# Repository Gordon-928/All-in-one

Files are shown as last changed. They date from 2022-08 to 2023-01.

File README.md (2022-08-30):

# All-in-one
Design and program of a small package data collection device
This project aims to learn the bascis of using STM32 MCU and PCB layout with MCU and sensors. The ultimate goal of the project is to develope a all-in-one sensor to collect flight data of a rocket, drop tests and other possible usage. Personal goal is to make a sensor close to commercial grade with all well-thought start-up sequence, easy to use and robust software.

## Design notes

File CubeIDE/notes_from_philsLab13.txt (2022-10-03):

STM32 CUBEIDE
CLOCK SETTING
- Set required clock source and run clock solver

SPI SETTING
- Change prescaler to change the baud rate (this step is mainly to tune to the required baud rate)

TIMER SETTING - PWM
- Change prescaler to change PWM freq
- This depends on the clock that the timer is on, refer to datasheet
- Look for the clock frequecny and change the prescaler to achieve desired frequency
	- e.g: want to scale down the timer clock from 84 MHz (APB1) to 10 Hz
	       i) Prescaler set to => 8400-1 (84e6 / 8400 = 10k) //set the freq of the counter is changed
              ii) counter period set to 100-1 (10k/100 = 100Hz) //counter need to count to 100-1
              Note: 
 	      - the -1 offset is needed (counter start from 0, if we want a 16 bit timer to count 2^16 times, it just need to count from 0-2^16-1)
              - must check if counter exceed the size of the regiester xxbit timer (e.g. 16 bit timer has a max value of 2^16 = 65536)

link: https://electronics.stackexchange.com/questions/632838/prescaler-vs-counter-period-stm32
Ref: ST-AN4776 Rev 3 Applcation Notes

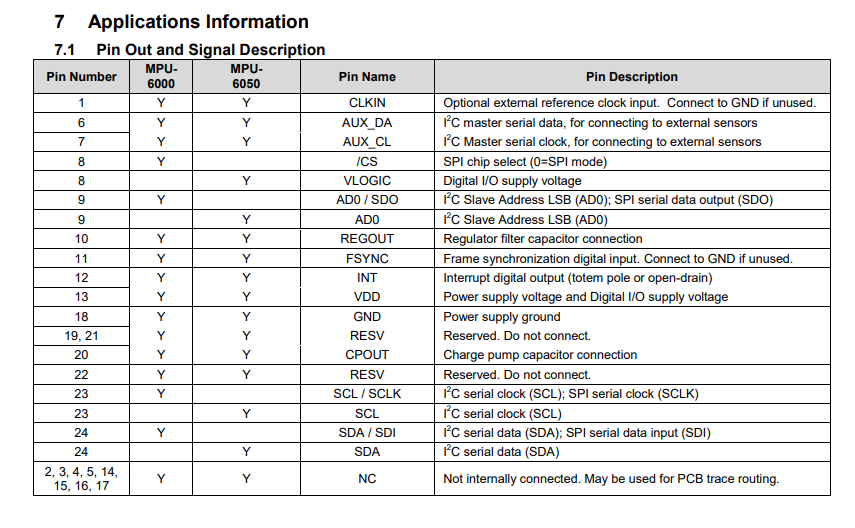
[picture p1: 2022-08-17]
Datasheets/MPU6050 Pinout.png

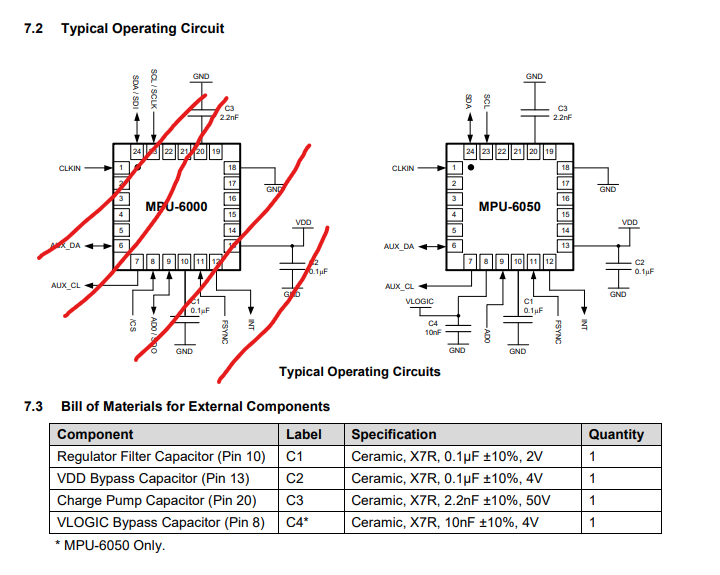
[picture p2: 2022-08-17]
Datasheets/MPU6050 Typical Circuit.png

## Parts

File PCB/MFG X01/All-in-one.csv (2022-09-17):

Item | Qty | Reference(s) | Value | LibPart | Footprint | Datasheet | JLCPCB Part# | LCSC | LCSC Part | PART ID
1 | 2 | C1, C3 | 22u | Device:C_Small | Capacitor_SMD:C_1206_3216Metric | ~ |  | C12891
2 | 1 | C2 | 1u | Device:C_Small | Capacitor_SMD:C_0805_2012Metric | ~ |  | C2798196
3 | 8 | C4, C8, C9, C10, C11, C16, C18, C19 | 100n | Device:C_Small | Capacitor_SMD:C_0402_1005Metric | ~ | C307331 | C307331 | C307331
4 | 1 | C5 | 1u | Device:C_Small | Capacitor_SMD:C_0603_1608Metric | ~ | C15849 | C15849 | C15849
5 | 2 | C6, C17 | 10n | Device:C_Small | Capacitor_SMD:C_0402_1005Metric | ~ | C15195 | C15195 | C15195
6 | 2 | C7, C14 | 4u7 | Device:C_Small | Capacitor_SMD:C_0603_1608Metric | ~ | C19666 | C19666 | C19666
7 | 2 | C12, C13 | 12p | Device:C_Small | Capacitor_SMD:C_0402_1005Metric | ~ | C1547 | C1547 | C1547
8 | 1 | C15 | 10u | Device:C_Small | Capacitor_SMD:C_0603_1608Metric | ~ | C96446 | C96446 | C96446
9 | 1 | C20 | 2n2 | Device:C_Small | Capacitor_SMD:C_0402_1005Metric | ~ | C1531 | C1531 | C1531
10 | 1 | D1 | B5819W | Device:D_Schottky_Small | Diode_SMD:D_SOD-123 | ~ | C8598 | C8598 | C8598
11 | 1 | D2 | LED_RED | Device:LED_Small | LED_SMD:LED_0603_1608Metric | ~ |  | C965799
12 | 1 | D3 | LED_GREEN | Device:LED | LED_SMD:LED_0603_1608Metric | ~ | C87326 | C965805 | C87326
13 | 1 | F1 | 250mA | Device:Polyfuse | Fuse:Fuse_1206_3216Metric | ~ | C269113 | C269113 | C269113 | SMD1206B025TF/24
14 | 1 | FB1 | 600 @ 100MHz | Device:FerriteBead_Small | Inductor_SMD:L_1206_3216Metric | ~ | C73732 | C73732 | C73732
15 | 4 | H1, H2, H3, H4 | MountingHole_Pad | Mechanical:MountingHole_Pad | MountingHole:MountingHole_3.5mm_Pad_Via | ~
16 | 1 | J1 | HIGH VOLTAGE | Connector:Screw_Terminal_01x02 | TerminalBlock_TE-Connectivity:TerminalBlock_TE_282834-2_1x02_P2.54mm_Horizontal | ~
17 | 1 | J2 | Micro_SD_Card_Det | Connector:Micro_SD_Card_Det | All-in-one-custom:SD_Card_custom | https://www.hirose.com/product/en/download_file/key_name/DM3/category/Catalog/doc_file_id/49662/?item_id=195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
18 | 1 | J3 | USB_C_Receptacle_USB2.0 | Connector:USB_C_Receptacle_USB2.0 | All-in-one-custom:USB_C_16PIN | https://www.usb.org/sites/default/files/documents/usb_type-c.zip
19 | 1 | J4 | I2C_EXT | Connector_Generic:Conn_01x04 | Connector_PinHeader_2.54mm:PinHeader_1x04_P2.54mm_Vertical | ~
20 | 1 | J5 | GPIO | Connector_Generic:Conn_01x04 | Connector_PinHeader_2.54mm:PinHeader_1x04_P2.54mm_Vertical | ~
21 | 1 | J6 | SWD | Connector_Generic:Conn_02x05_Odd_Even | Connector_PinHeader_2.54mm:PinHeader_2x05_P2.54mm_Vertical | ~
22 | 2 | J7, J8 | Conn_01x02 | Connector_Generic:Conn_01x02 | Connector_PinHeader_2.54mm:PinHeader_1x02_P2.54mm_Vertical | ~
23 | 1 | J9 | UART_EXT | Connector_Generic:Conn_01x04 | Connector_PinHeader_2.54mm:PinHeader_1x04_P2.54mm_Vertical | ~
24 | 1 | L1 | 22u | Device:L_Small | All-in-one-custom:MPIT8040 | ~ |  | C281320
25 | 1 | L2 | 39n | Device:L_Small | Inductor_SMD:L_0402_1005Metric | ~ | C86063 | C86063 | C86063
26 | 1 | Q1 | AO3401A | Transistor_FET:AO3401A | Package_TO_SOT_SMD:SOT-23 | http://www.aosmd.com/pdfs/datasheet/AO3401A.pdf | C15127 | C15127 | C15127
27 | 1 | R1 | 75k | Device:R_Small | Resistor_SMD:R_0603_1608Metric | ~ |  | C18671
28 | 1 | R2 | 40k2 | Device:R_Small | Resistor_SMD:R_0603_1608Metric | ~ |  | C25893
29 | 2 | R3, R4 | 13k | Device:R_Small | Resistor_SMD:R_0603_1608Metric | ~ |  | C2907101
30 | 3 | R5, R8, R11 | 10k | Device:R_Small | Resistor_SMD:R_0402_1005Metric | ~ | C25744 | C25744 | C25744
31 | 1 | R6 | 510 | Device:R_Small | Resistor_SMD:R_0402_1005Metric | ~ | C25123 | C25123 | C25123
32 | 1 | R7 | 1k | Device:R_Small | Resistor_SMD:R_0603_1608Metric | ~ | C21190 | C21190 | C21190
33 | 2 | R9, R10 | 2k2 | Device:R_Small | Resistor_SMD:R_0603_1608Metric | ~ | C4190 | C4190 | C4190
34 | 2 | R12, R13 | 5k1 | Device:R_Small | Resistor_SMD:R_0402_1005Metric | ~ | C25905 | C25905 | C25905
35 | 1 | SW1 | SW_Push | Switch:SW_Push | All-in-one-custom:GT-TC029 | ~ | C843669 | C843669 | C843669
36 | 1 | SW2 | BOOT | Switch:SW_Push | All-in-one-custom:GT-TC029 | ~ | C843669 | C843669 | C843669
37 | 1 | U1 | TPMP1470 | All-in-one_custom:TPMP1470 | Package_TO_SOT_SMD:SOT-23-6 |  |  | C558426
38 | 1 | U2 | STM32F401CDUx | MCU_ST_STM32F4:STM32F401CDUx | Package_DFN_QFN:QFN-48-1EP_7x7mm_P0.5mm_EP5.6x5.6mm | http://www.st.com/st-web-ui/static/active/en/resource/technical/document/datasheet/DM00102166.pdf
39 | 1 | U3 | BMP280 | Sensor_Pressure:BMP280 | Package_LGA:Bosch_LGA-8_2x2.5mm_P0.65mm_ClockwisePinNumbering | https://ae-bst.resource.bosch.com/media/_tech/media/datasheets/BST-BMP280-DS001.pdf
40 | 1 | U4 | MPU-6050 | Sensor_Motion:MPU-6050 | Sensor_Motion:InvenSense_QFN-24_4x4mm_P0.5mm | https://store.invensense.com/datasheets/invensense/MPU-6050_DataSheet_V3%204.pdf
41 | 1 | U5 | USBLC6-2P6 | Power_Protection:USBLC6-2P6 | Package_TO_SOT_SMD:SOT-666 | https://www.st.com/resource/en/datasheet/usblc6-2.pdf | C2827693 | C2827693 | C2827693
42 | 1 | Y1 | 25MHz 12pF | Device:Crystal_GND24_Small | Crystal:Crystal_SMD_3225-4Pin_3.2x2.5mm | ~ | C9006 | C9006 | C9006 | X322525MOB4SI

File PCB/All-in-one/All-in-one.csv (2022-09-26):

Qty | LCSC Part Number
2 | C13585
1 | C24497
3 | C28233
2 | C12891
8 | C307331
1 | C15849
2 | C15195
2 | C19666
2 | C1547
1 | C96446
1 | C1531
3 | C15850
1 | C8598
1 | C72041
1 | C2286
1 | C87326
2 | C269113
1 | C73732
4
1
1
1
1
1
2
1
1
1
1 | C135262
1 | C86063
1 | C15127
1 | C23003
3 | C25804
1 | C22843
2 | C22797
2 | C21190
3 | C25744
1 | C25123
2 | C4190
2 | C25905
1 | C145841
1 | C843669
1 | C843669
1 | C116592
1 | C133056
1
1
1
1 | C2827693
2 | C89855
1 | C9006

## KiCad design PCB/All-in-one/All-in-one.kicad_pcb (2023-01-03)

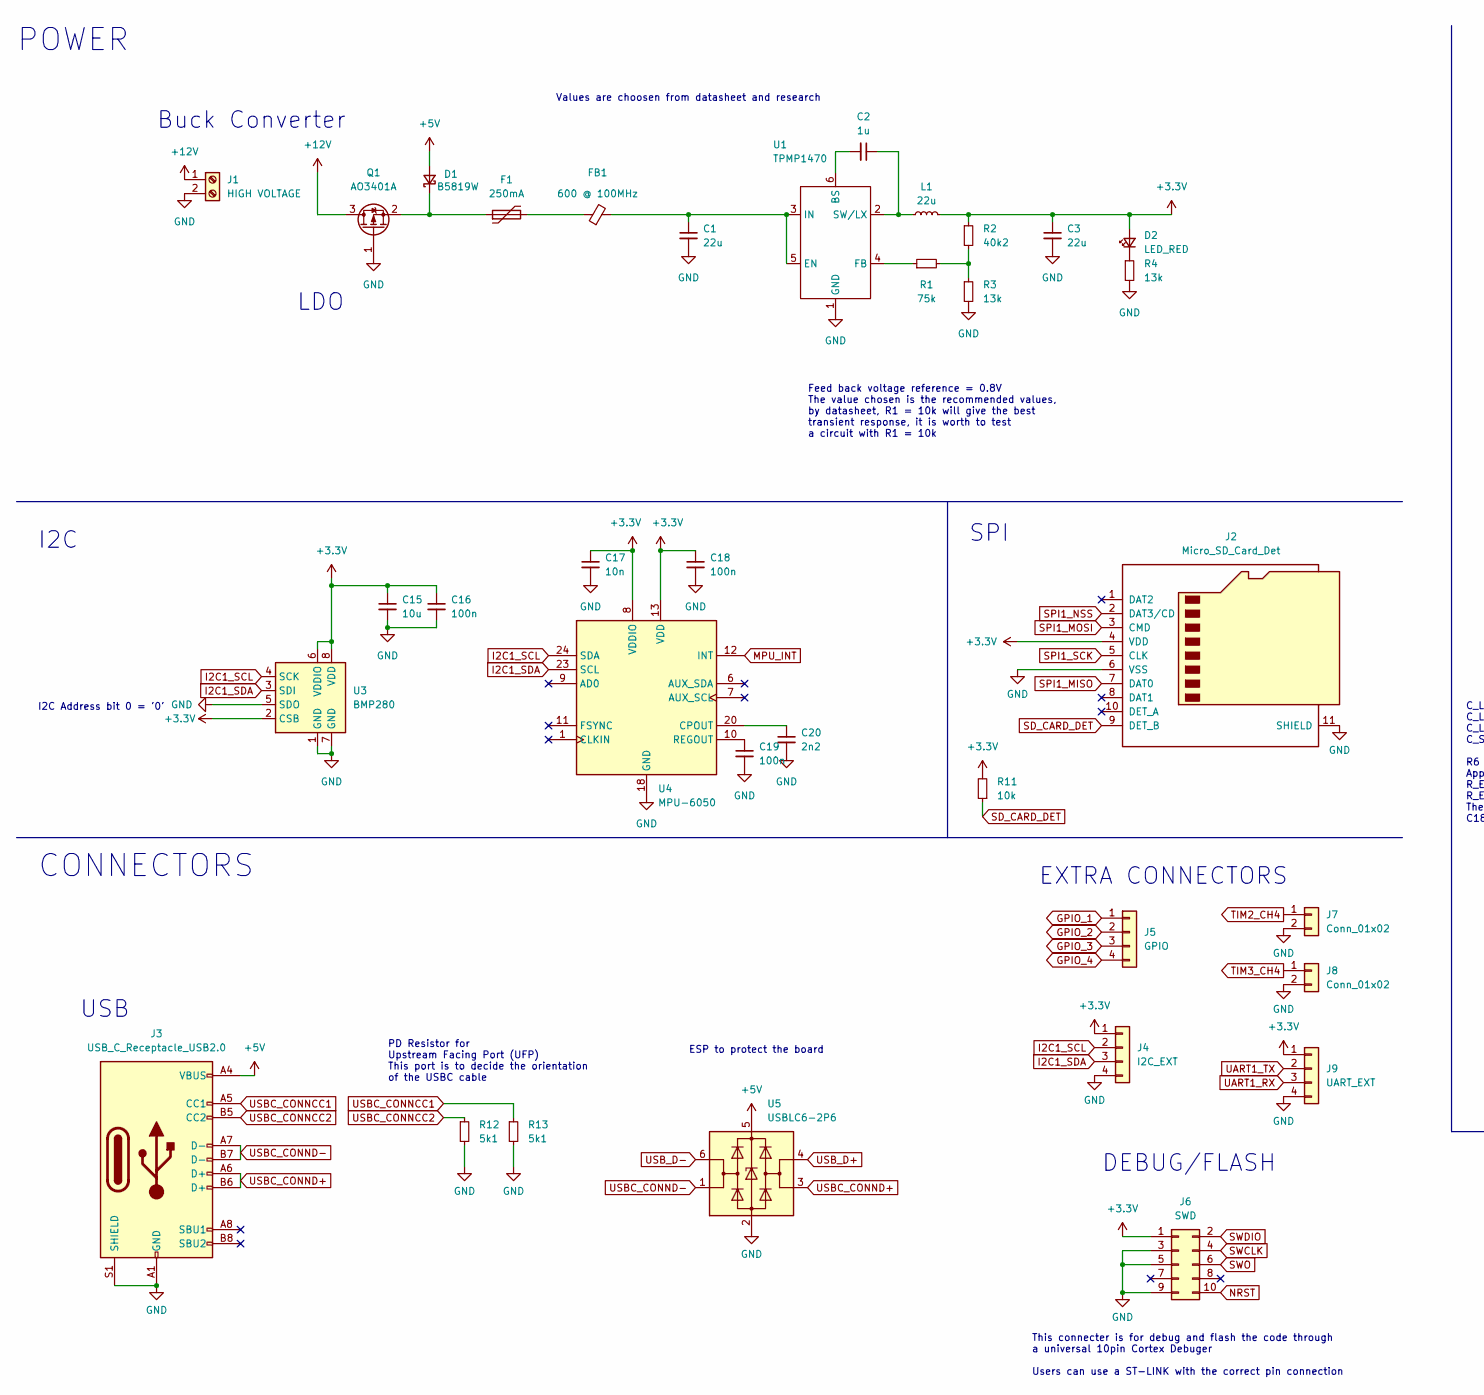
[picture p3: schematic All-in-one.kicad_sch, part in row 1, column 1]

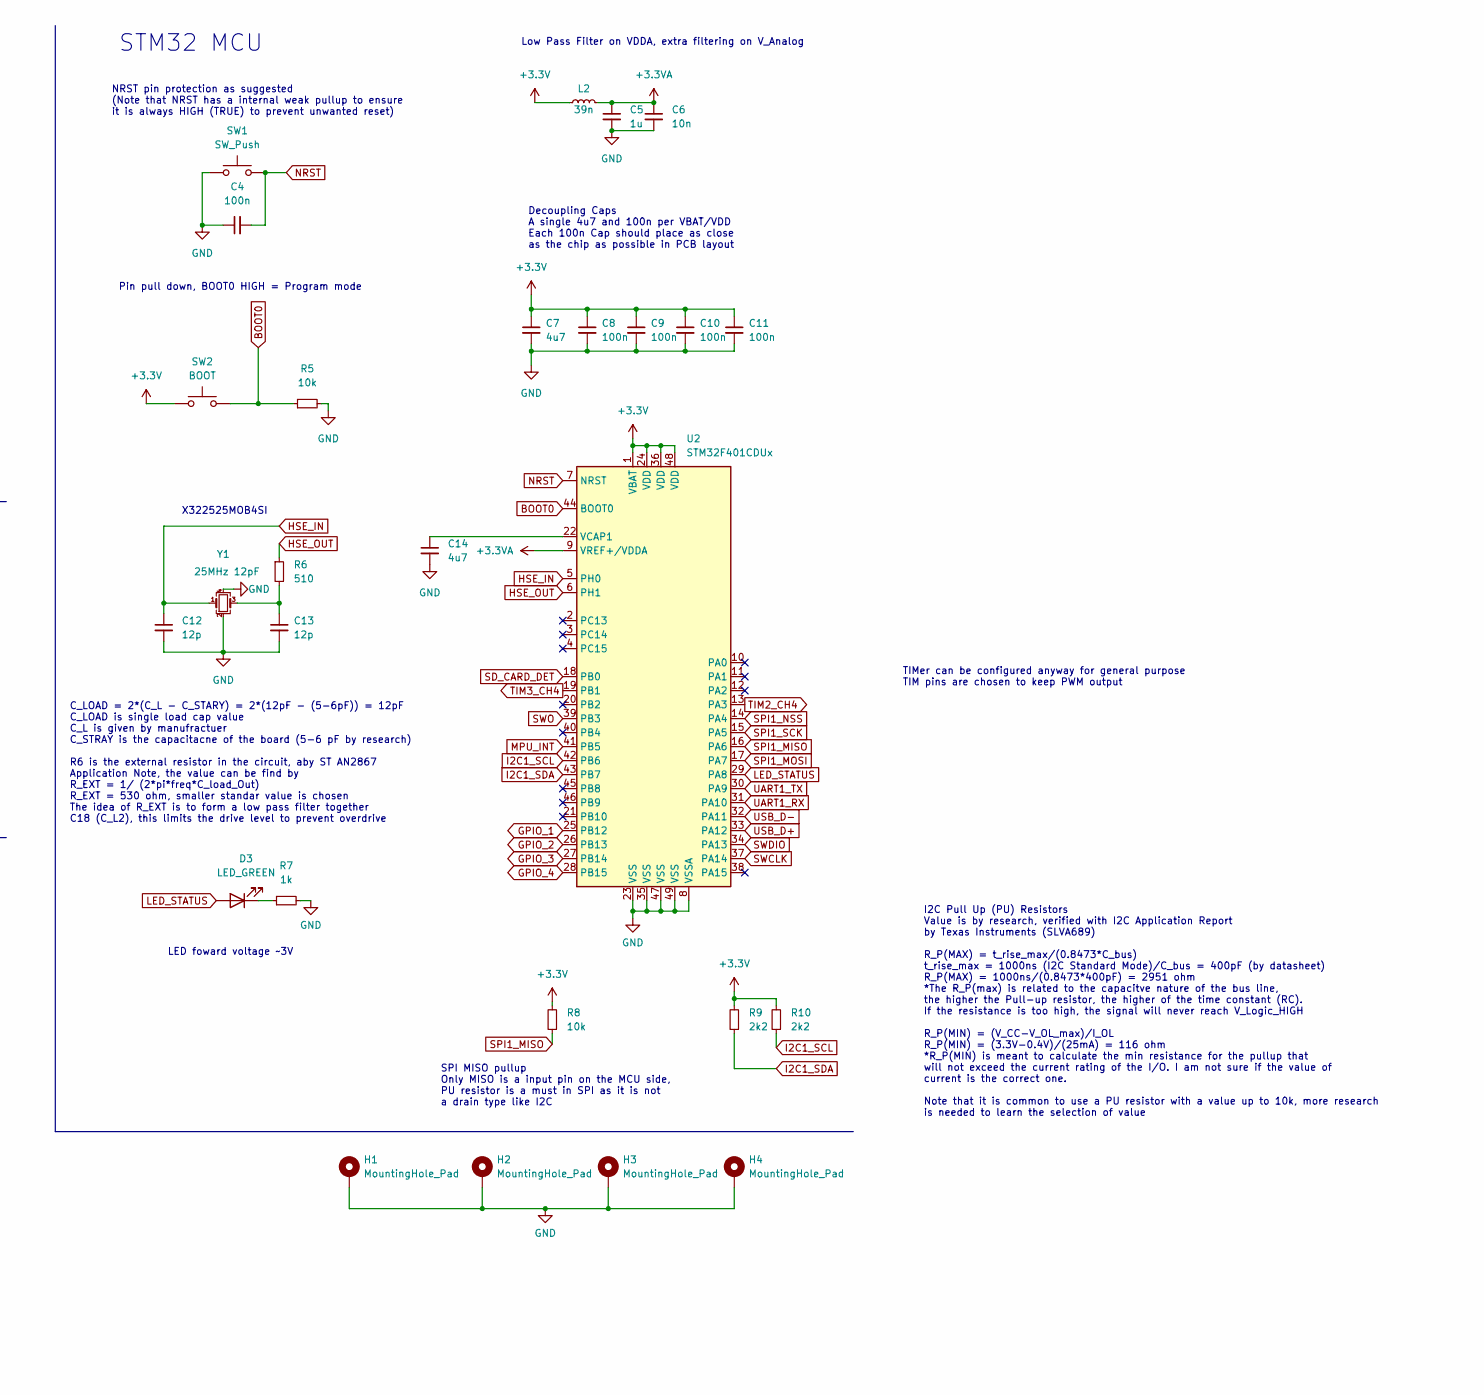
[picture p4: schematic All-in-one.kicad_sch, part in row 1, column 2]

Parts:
C1, C3: 22u; C_1206_3216Metric; LCSC C12891
C2: 1u; C_0805_2012Metric; LCSC C2798196
C4, C8, C9, C10, C11, C16, C18, C19: 100n; C_0402_1005Metric; JLCPCB Part# C307331
C5: 1u; C_0603_1608Metric; JLCPCB Part# C15849
C6, C17: 10n; C_0402_1005Metric; JLCPCB Part# C15195
C7, C14: 4u7; C_0603_1608Metric; JLCPCB Part# C19666
C12, C13: 12p; C_0402_1005Metric; JLCPCB Part# C1547
C15: 10u; C_0603_1608Metric; JLCPCB Part# C96446
C20: 2n2; C_0402_1005Metric; JLCPCB Part# C1531
D1: B5819W; D_SOD-123; JLCPCB Part# C8598
D2: LED_RED; LED_0603_1608Metric; LCSC C965799
D3: LED_GREEN; LED_0603_1608Metric; JLCPCB Part# C87326
F1: 250mA; Fuse_1206_3216Metric; PART ID SMD1206B025TF/24; JLCPCB Part# C269113
FB1: 600 @ 100MHz; L_1206_3216Metric; JLCPCB Part# C73732
H1, H2, H3, H4: MountingHole_Pad; MountingHole_3.5mm_Pad_Via
J1: HIGH VOLTAGE; TerminalBlock_TE_282834-2_1x02_P2.54mm_Horizontal
J2: Micro_SD_Card_Det; SD_Card_custom
J3: USB_C_Receptacle_USB2.0; USB_C_16PIN
J4: I2C_EXT; PinHeader_1x04_P2.54mm_Vertical
J5: GPIO; PinHeader_1x04_P2.54mm_Vertical
J6: SWD; PinHeader_2x05_P2.54mm_Vertical
J7, J8: Conn_01x02; PinHeader_1x02_P2.54mm_Vertical
J9: UART_EXT; PinHeader_1x04_P2.54mm_Vertical
L1: 22u; MPIT8040; LCSC C281320
L2: 39n; L_0402_1005Metric; JLCPCB Part# C86063
Q1: AO3401A; SOT-23; JLCPCB Part# C15127
R1: 75k; R_0603_1608Metric; LCSC C18671
R2: 40k2; R_0603_1608Metric; LCSC C25893
R3, R4: 13k; R_0603_1608Metric; LCSC C2907101
R5, R8, R11: 10k; R_0402_1005Metric; JLCPCB Part# C25744
R6: 510; R_0402_1005Metric; JLCPCB Part# C25123
R7: 1k; R_0603_1608Metric; JLCPCB Part# C21190
R9, R10: 2k2; R_0603_1608Metric; JLCPCB Part# C4190
R12, R13: 5k1; R_0402_1005Metric; JLCPCB Part# C25905
SW1: SW_Push; GT-TC029; JLCPCB Part# C843669
SW2: BOOT; GT-TC029; JLCPCB Part# C843669
U1: TPMP1470; SOT-23-6; LCSC C558426
U2: STM32F401CDUx; QFN-48-1EP_7x7mm_P0.5mm_EP5.6x5.6mm
U3: BMP280; Bosch_LGA-8_2x2.5mm_P0.65mm_ClockwisePinNumbering
U4: MPU-6050; InvenSense_QFN-24_4x4mm_P0.5mm
U5: USBLC6-2P6; SOT-666; JLCPCB Part# C2827693
Y1: 25MHz 12pF; Crystal_SMD_3225-4Pin_3.2x2.5mm; PART ID X322525MOB4SI; JLCPCB Part# C9006

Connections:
+3.3V: C3.1, C7.1, C8.1, C9.1, C10.1, C11.1, C15.1, C16.1, C17.1, C18.1, D2.2 (A), J2.4 (VDD), J4.1, J6.1, J9.1, L1.2, L2.1, R2.1, R8.2, R9.2, R10.2, R11.2, SW2.1, U2.1 (VBAT), U2.24 (VDD), U2.36 (VDD), U2.48 (VDD), U3.2 (CSB), U3.6 (VDDIO), U3.8 (VDD), U4.8 (VDDIO), U4.13 (VDD)
+3.3VA: C5.1, C6.1, L2.2, U2.9 (VREF+/VDDA)
+5V: D1.2 (A), J3.A4 (VBUS), J3.A9 (VBUS), J3.B4 (VBUS), J3.B9 (VBUS), U5.5 (VBUS)
+12V: J1.1, Q1.3 (D)
BOOT0: R5.1, SW2.2, U2.44 (BOOT0)
GND: C1.2, C3.2, C4.1, C5.2, C6.2, C7.2, C8.2, C9.2, C10.2, C11.2, C12.2, C13.2, C14.2, C15.2, C16.2, C17.2, C18.2, C19.2, C20.2, H1.1, H2.1, H3.1, H4.1, J1.2, J2.6 (VSS), J2.11 (SHIELD), J3.A1 (GND), J3.A12 (GND), J3.B1 (GND), J3.B12 (GND), J3.S1 (SHIELD), J4.4, J6.3, J6.5, J6.9, J7.2, J8.2, J9.4, Q1.1 (G), R3.2, R4.2, R5.2, R7.2, R12.2, R13.2, SW1.1, U1.1 (GND), U2.8 (VSSA), U2.23 (VSS), U2.35 (VSS), U2.47 (VSS), U2.49 (VSS), U3.1 (GND), U3.5 (SDO), U3.7 (GND), U4.18 (GND), U5.2 (GND), Y1.2, Y1.4
GPIO_1: J5.1, U2.25 (PB12)
GPIO_2: J5.2, U2.26 (PB13)
GPIO_3: J5.3, U2.27 (PB14)
GPIO_4: J5.4, U2.28 (PB15)
HSE_IN: C12.1, U2.5 (PH0), Y1.1
HSE_OUT: R6.1, U2.6 (PH1)
I2C1_SCL: J4.2, R10.1, U2.42 (PB6), U3.4 (SCK), U4.24 (SDA)
I2C1_SDA: J4.3, R9.1, U2.43 (PB7), U3.3 (SDI), U4.23 (SCL)
LED_STATUS: D3.2 (A), U2.29 (PA8)
MPU_INT: U2.41 (PB5), U4.12 (INT)
NRST: C4.2, J6.10, SW1.2, U2.7 (NRST)
unnamed: C1.1, FB1.2, U1.3 (IN), U1.5 (EN)
unnamed: C2.1, L1.1, U1.2 (SW/LX)
unnamed: C2.2, U1.6 (BS)
unnamed: C13.1, R6.2, Y1.3
unnamed: C14.1, U2.22 (VCAP1)
unnamed: C19.1, U4.10 (REGOUT)
unnamed: C20.1, U4.20 (CPOUT)
unnamed: D1.1 (K), F1.1, Q1.2 (S)
unnamed: D2.1 (K), R4.1
unnamed: D3.1 (K), R7.1
unnamed: F1.2, FB1.1
unnamed: R1.1, U1.4 (FB)
unnamed: R1.2, R2.2, R3.1
SD_CARD_DET: J2.9 (DET_B), R11.1, U2.18 (PB0)
SPI1_MISO: J2.7 (DAT0), R8.1, U2.16 (PA6)
SPI1_MOSI: J2.3 (CMD), U2.17 (PA7)
SPI1_NSS: J2.2 (DAT3/CD), U2.14 (PA4)
SPI1_SCK: J2.5 (CLK), U2.15 (PA5)
SWCLK: J6.4, U2.37 (PA14)
SWDIO: J6.2, U2.34 (PA13)
SWO: J6.6, U2.39 (PB3)
TIM2_CH4: J7.1, U2.13 (PA3)
TIM3_CH4: J8.1, U2.19 (PB1)
UART2_RX: J9.3, U2.31 (PA10)
UART2_TX: J9.2, U2.30 (PA9)
USBC_CONNCC1: J3.A5 (CC1), R13.1
USBC_CONNCC2: J3.B5 (CC2), R12.1
USBC_CONND+: J3.A6 (D+), J3.B6 (D+), U5.3 (I/O2)
USBC_CONND-: J3.A7 (D-), J3.B7 (D-), U5.1 (I/O1)
USB_D+: U2.33 (PA12), U5.4 (I/O2)
USB_D-: U2.32 (PA11), U5.6 (I/O1)

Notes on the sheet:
TIMer can be configured anyway for general purpose TIM pins are chosen to keep PWM output
Buck Converter
PD Resistor for Upstream Facing Port (UFP) This port is to decide the orientation of the USBC cable
SPI
This connecter is for debug and flash the code through a universal 10pin Cortex Debuger Users can use a ST-LINK with the correct pin connection
DEBUG/FLASH
I2C Address bit 0 = '0'
I2C Pull Up (PU) Resistors Value is by research, verified with I2C Application Report by Texas Instruments (SLVA689) R_P(MAX) = t_rise_max/(0.8473*C_bus) t_rise_max = 1000ns (I2C Standard Mode)/C_bus = 400pF (by datasheet) R_P(MAX) = 1000ns/(0.8473*400pF) = 2951 ohm *The R_P(max) is related to the 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
EXTRA CONNECTORS
Feed back voltage reference = 0.8V The value chosen is the recommended values, by datasheet, R1 = 10k will give the best transient response, it is worth to test a circuit with R1 = 10k
Values are choosen from datasheet and research
SPI MISO pullup Only MISO is a input pin on the MCU side, PU resistor is a must in SPI as it is not a drain type like I2C
LED foward voltage ~3V
STM32 MCU
X322525MOB4SI
ESP to protect the board
I2C
POWER
Low Pass Filter on VDDA, extra filtering on V_Analog
C_LOAD = 2*(C_L - C_STARY) = 2*(12pF - (5-6pF)) = 12pF C_LOAD is single load cap value C_L is given by manufractuer C_STRAY is the capacitacne of the board (5-6 pF by research) R6 is the external resistor in the circuit, aby ST AN2867 Application Note, the value can be find by R_EXT = 1/ (2*pi*freq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
USB
Decoupling Caps A single 4u7 and 100n per VBAT/VDD Each 100n Cap should place as close as the chip as possible in PCB layout
LDO
CONNECTORS
Pin pull down, BOOT0 HIGH = Program mode
NRST pin protection as suggested (Note that NRST has a internal weak pullup to ensure it is always HIGH (TRUE) to prevent unwanted reset)

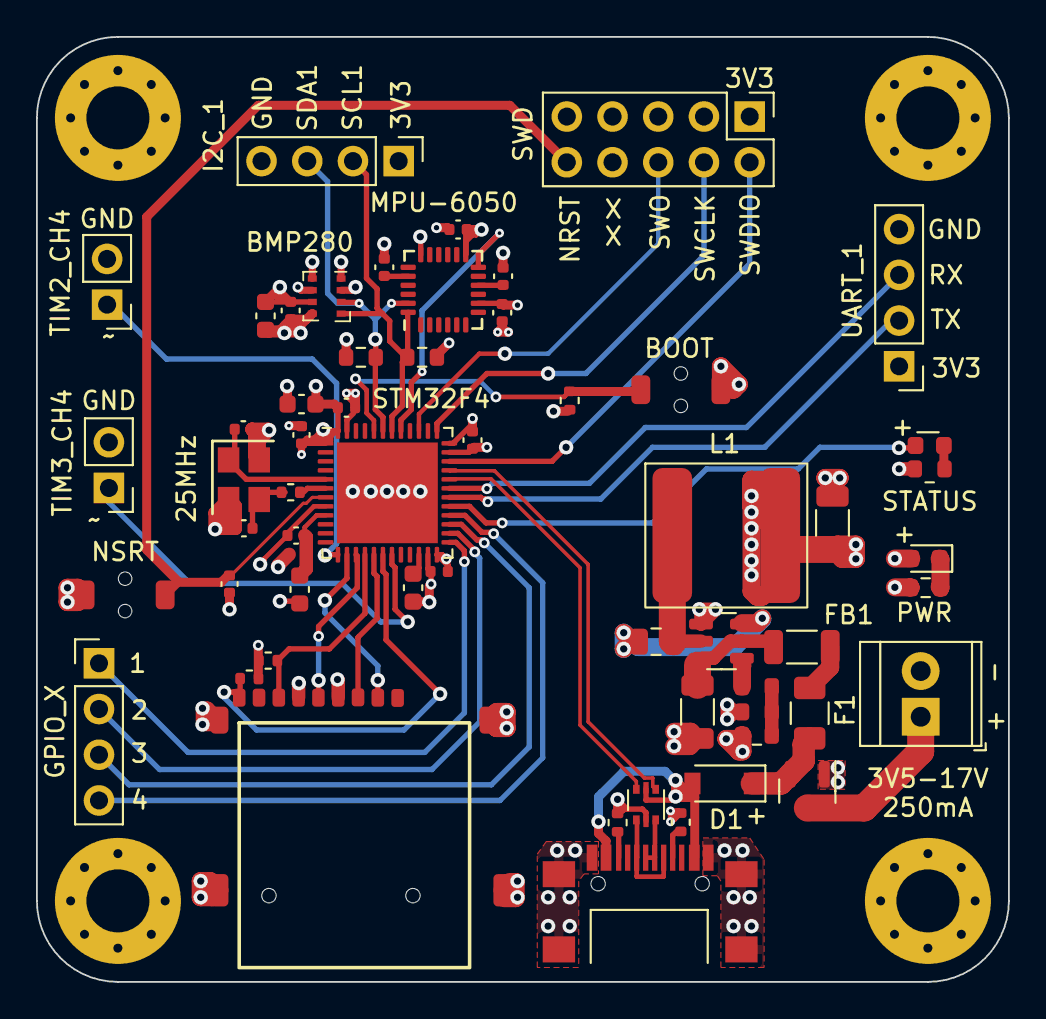
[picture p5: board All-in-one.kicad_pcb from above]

Board: 4 copper layers, 54.0 x 52.5 mm, 62 parts (0 on the bottom side), 48 nets.

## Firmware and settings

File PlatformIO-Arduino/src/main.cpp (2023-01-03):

#include <Arduino.h>
#include "Wire.h"
#include "SPI.h"
#include "SD.h"
#include "Adafruit_BMP280.h"
#include "Adafruit_MPU6050.h"
#include "elapsedMillis.h"

//define I2C Pins
#define SCL_PIN 222
#define SDA_PIN 222

//define SD card SS pin
#define SD_SS 9 

Adafruit_BMP280 bmp;
//Adafruit_Sensor *bmp_pressure = bmp.getPressureSensor();
//Adafruit_Sensor *bmp_temp = bmp.getTemperatureSensor();
//sensors_event_t bmpTempEvent, pressureEvent;
#define bmp_ADDRESS 0x77
#define SEALEVELPRESSURE_HPA (1013.25)

Adafruit_MPU6050 mpu;
sensors_event_t a, w, mpuTemp;
#define mpu_ADDRESS 0x68

File myFile;

elapsedMicros elapsedTime;
#define dp 4
const char defaultDelim = ',';

void addToString(float sensorVal, String dataString, int decimalPlace = 4, char delim = defaultDelim){
  dataString += String(sensorVal, decimalPlace);
  dataString += delim;
}

void logData(){
  String dataString;
  addToString(elapsedTime, dataString, 1);
  //read mpu data
  mpu.getEvent(&a, &w, &mpuTemp);
   
  //read bmp
  bmp.takeForcedMeasurement();
  
  addToString(a.acceleration.x, dataString);
  addToString(a.acceleration.y, dataString);
  addToString(a.acceleration.z, dataString);
  addToString(w.gyro.x, dataString);
  addToString(w.gyro.y, dataString);
  addToString(w.gyro.z, dataString);

  addToString(bmp.readPressure(), dataString);
  addToString(bmp.readAltitude(), dataString);
  addToString(bmp.readTemperature(), dataString, 4, '\n');

  Serial.println(dataString);
}

void setup() {
  Wire.begin(); //TODO check which channel is used
  Wire.setSCL(SCL_PIN);
  Wire.setSDA(SDA_PIN);

  if(!mpu.begin(mpu_ADDRESS, &Wire)){
    //do something
  }
  mpu.setAccelerometerRange(MPU6050_RANGE_16_G);
  mpu.setGyroRange(MPU6050_RANGE_1000_DEG);
  mpu.setFilterBandwidth(MPU6050_BAND_21_HZ);


  if(!bmp.begin(bmp_ADDRESS)){
    //do something
  }
  bmp.setSampling(Adafruit_BMP280::MODE_NORMAL,     /* Operating Mode. */
                  Adafruit_BMP280::SAMPLING_X2,     /* Temp. oversampling */
                  Adafruit_BMP280::SAMPLING_X16,    /* Pressure oversampling */
                  Adafruit_BMP280::FILTER_X16,      /* Filtering. */
                  Adafruit_BMP280::STANDBY_MS_500); /* Standby time. */

  String header = "time(s), *C, Pa, Alt (m), ax (m/s^2), ay (m/s^2), az (m/s^2), wx (deg/s), wy (deg/s), wz (deg/s),";
  if (SD.begin(SD_SS)) {
    File dataFile = SD.open("DATA.txt", FILE_WRITE); //TODO add automatic increase file number
    dataFile.println(header);
    dataFile.close();
  }
}

void loop() {
  
  //store
  /*
  File dataFile = SD.open("data.txt", FILE_WRITE);
  dataFile.println(dataString);
  dataFile.close();
  delay(1);
  */
}

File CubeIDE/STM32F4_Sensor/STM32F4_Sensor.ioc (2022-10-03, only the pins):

Mcu.UserName=STM32F401CDUx
PA10.Signal=USB_OTG_FS_ID
PA11.Signal=USB_OTG_FS_DM
PA12.Signal=USB_OTG_FS_DP
PA13.Signal=SYS_JTMS-SWDIO
PA14.Signal=SYS_JTCK-SWCLK
PA3.Signal=S_TIM2_CH4
PA4.Signal=SPI1_NSS
PA5.Signal=SPI1_SCK
PA6.Signal=SPI1_MISO
PA7.Signal=SPI1_MOSI
PA8.GPIO_Label=LED_STATUS
PA8.Signal=GPIO_Output
PA9.Signal=USART1_TX
PB0.Signal=GPIO_Input
PB1.Signal=S_TIM3_CH4
PB12.GPIO_Label=GPIO_1
PB12.Signal=GPIO_Output
PB13.Signal=GPIO_Output
PB14.GPIO_Label=GPIO_3
PB14.Signal=GPIO_Output
PB15.GPIO_Label=GPIO_4
PB15.Signal=GPIO_Output
PB3.Signal=SYS_JTDO-SWO
PB5.GPIO_Label=MPU_INT
PB5.Signal=GPIO_Input
PB6.Signal=I2C1_SCL
PB7.Signal=USART1_RX
PB9.Signal=I2C1_SDA

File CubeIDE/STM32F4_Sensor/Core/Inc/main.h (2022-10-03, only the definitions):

#define GPIO_1_Pin GPIO_PIN_12
#define GPIO_1_GPIO_Port GPIOB
#define GPIO_3_Pin GPIO_PIN_14
#define GPIO_3_GPIO_Port GPIOB
#define GPIO_4_Pin GPIO_PIN_15
#define GPIO_4_GPIO_Port GPIOB
#define LED_STATUS_Pin GPIO_PIN_8
#define LED_STATUS_GPIO_Port GPIOA
#define MPU_INT_Pin GPIO_PIN_5
#define MPU_INT_GPIO_Port GPIOB

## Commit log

2022-08-15 Project Initialization
    - Initialize KiCAD project
    - Uploaded datasheets
    [All-in-one.kicad_pcb, All-in-one.kicad_sch]
2022-08-28 Added draft schematic and STM32CubeIDE Project - Added all datasheets
    - Started schematic draftin
    - Started STM32C
    [All-in-one.kicad_sch]
2022-08-28 Push All Project Files to Repo - All files include STM32CubeIDE project files, untracked documents
2022-08-30 Draft Schematic - Schematic is 80%ish done, details on minor connections need more research - Wired sensors - Added extra connectors - SD card slot is NOT wired
    [All-in-one.kicad_sch]
2022-08-30 Minor Update
    [All-in-one.kicad_sch]
2022-08-31 Pin Finalize and Added SD Card Slot Via SPI - Pin and circuit are ready to final check - Added LDO for Lipo, a power source switch should be added
    [All-in-one.kicad_sch]
2022-09-02 REV X01 Schematic Completed - Schematic is completed, with the purpose of X01 being the proto board - External resistor of the external clock is left as a pad only, it is a bit unclear that if a exte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
    [All-in-one.kicad_sch]
2022-09-02 Updated Schematic and Footprint Assignments
    - Updated power supply circuit switch
    - Added custom foot prints
    - Assigned most of the footprints
    [All-in-one.kicad_sch]
2022-09-05 Updated PCB Layout
    [All-in-one.kicad_pcb, All-in-one.kicad_sch]
2022-09-09 Recovery File
    [All-in-one.kicad_pcb]
2022-09-09 Completed PCB Layout (No Tracing) - Made PCB layout - Tracing need to be done
    [All-in-one.kicad_pcb, All-in-one.kicad_sch]
2022-09-11 Ver X01 PCB Routing Completed - PCB is completed and all MFG files are exported - gbr files are uploaded to JLCPCB for quoting - All parts needed to be sourced - Encounterd some bug at using CubeIDE
    [All-in-one.kicad_pcb, All-in-one.kicad_sch]
2022-09-12 Production Files Updated - Sent to JLCPCB for manufracturing - No SMD parts can be shipped with the order, to reduce the cost, it is most likely that a pre-assembled PCB will be ordered
    [All-in-one.kicad_pcb, All-in-one.kicad_sch]
2022-09-13 git add -A all missing files
    [All-in-one-B_Cu.gbr, All-in-one-B_Mask.gbr, All-in-one-B_Paste.gbr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]
2022-09-14 Updated Circuit - Based on the new parts supplier LCSC, better components can be found - PCB is updated according to the new components
    [All-in-one.kicad_pcb, All-in-one.kicad_sch]
2022-09-15 PCB Tracing Update - Reroute traces
    [All-in-one.kicad_pcb]
2022-09-17 PCB Update - PCB is good to go - Order is on hold as there maybe other projects that requires ordering
    [All-in-one-B_Cu.gbr, All-in-one-B_Mask.gbr, All-in-one-B_Paste.gbr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]
2022-09-18 VER X01 Final Production Files - As the PCB is ordered, X01 is completed and wait for testing - The PCB is MFG as is in this commit
    [All-in-one.kicad_pcb]
2022-09-26 Added .gitignore
    [All-in-one.csv]
2022-10-02 Added KiCAD gitignore
2022-10-03 Updated CubeIDE Code and Reviewed All-in-one X01 PCB - updated PCB labelling (UART_1 is mis-labelled as UART_2 on both .sch and PCB) - Tried STM32 programming with simple PWM code
    [All-in-one-B_Cu.gbr, All-in-one-B_Mask.gbr, All-in-one-B_Paste.gbr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]
2023-01-03 Added code with Arduino framework - added code with arduino framework for other project testing - added dimension for PCB mounting holes
    [All-in-one.kicad_pcb]

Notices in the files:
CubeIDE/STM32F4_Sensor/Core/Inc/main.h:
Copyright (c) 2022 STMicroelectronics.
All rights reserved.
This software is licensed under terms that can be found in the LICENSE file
